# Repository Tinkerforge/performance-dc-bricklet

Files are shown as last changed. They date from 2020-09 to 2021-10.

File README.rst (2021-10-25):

Performance DC Bricklet
=======================

This repository contains the firmware source code and the hardware design
files. The documentation generator configs can be found at
https://github.com/Tinkerforge/generators

Repository Content
------------------

software/:
 * examples/: Examples for all supported languages
 * build/: Compiled files
 * src/: Source code of firmware
 * Makefile: Makefile to build project

hardware/:
 * Contains KiCad project files and additionally schematics as PDF

datasheets/:
 * Contains datasheets for sensors and complex ICs that are used

Hardware
--------

The hardware is designed with the open source EDA Suite KiCad
(http://www.kicad.org). Before you are able to open the files,
you have to install the Tinkerforge kicad-libraries
(https://github.com/Tinkerforge/kicad-libraries). You can either clone
them directly in hardware/ or clone them in a separate folder and
symlink them into hardware/
(ln -s kicad_path/kicad-libraries project_path/hardware). After that you
can open the .pro file in hardware/ with KiCad and from there view and
modify the schematics and the PCB layout.

Software
--------

If you want to do your own Brick/Bricklet firmware development we highly
recommend that you use our build environment setup script and read the
tutorial (https://www.tinkerforge.com/en/doc/Tutorials/Tutorial_Build_Environment/Tutorial.html).

To compile the C code we recommend you to install the newest GNU Arm Embedded
Toolchain (https://launchpad.net/gcc-arm-embedded/+download).
You also need to install bricklib2 (https://github.com/Tinkerforge/bricklib2).

You can either clone it directly in software/src/ or clone it in a
separate folder and symlink it into software/src/
(ln -s bricklib_path/bricklib2 project_path/software/src/). Finally make sure to
have CMake installed (http://www.cmake.org/cmake/resources/software.html).

After that you can build the firmware by invoking make in software/.
The firmware (.zbin) can then be found in software/build/ and uploaded
with brickv (click button "Flashing" on start screen).

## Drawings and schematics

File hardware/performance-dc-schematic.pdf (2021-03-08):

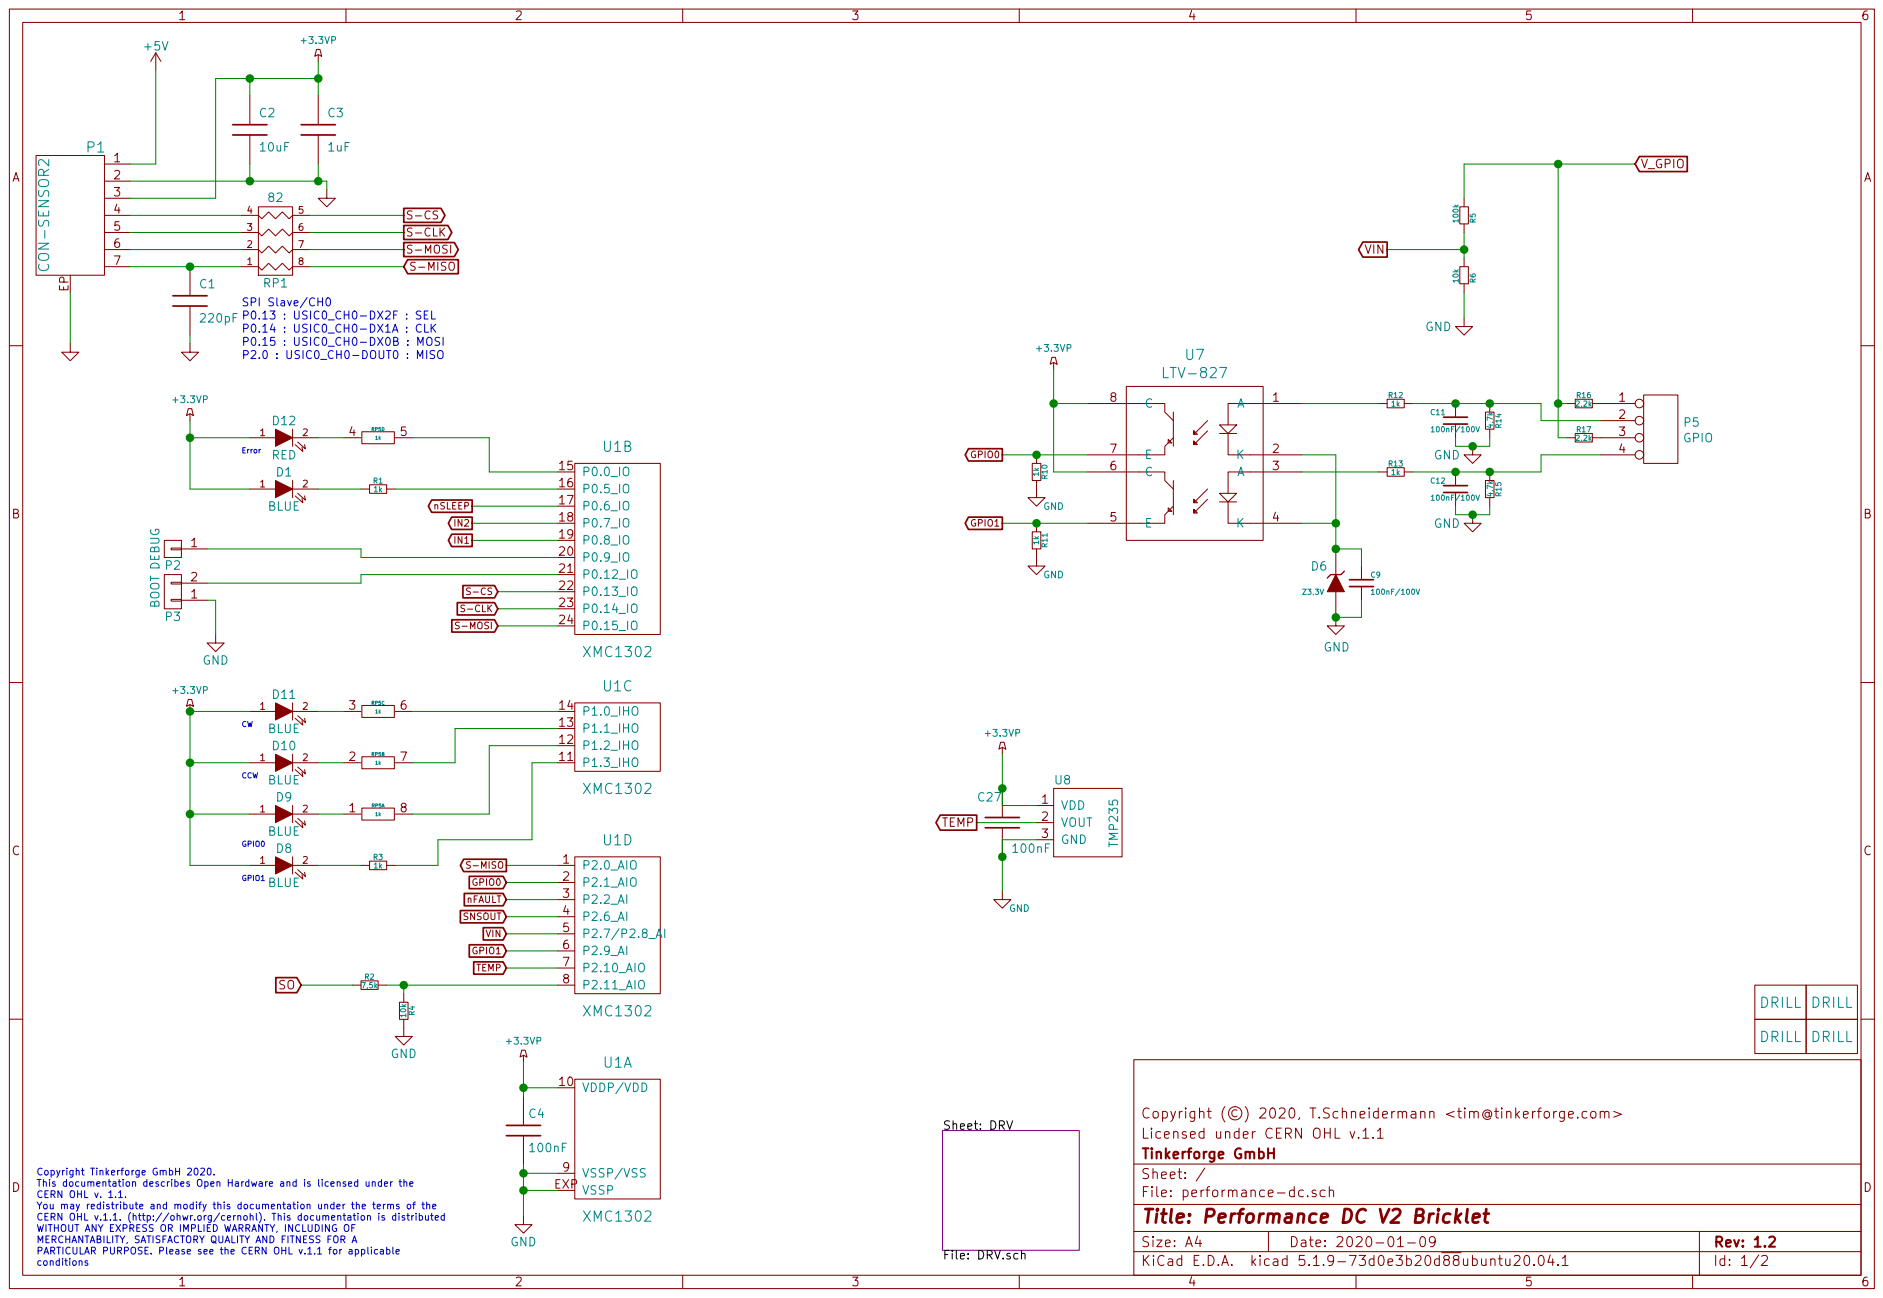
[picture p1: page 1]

SPI Slave/CH0 P0.13 : USIC0_CH0-DX2F : SEL P0.14 : USIC0_CH0-DX1A : CLK

Licensed under CERN OHL v.1.1 Copyright (©) 2020, T.Schneidermann <tim@tinkerforge.com>

File: performance-dc.sch Sheet: / Tinkerforge GmbH

Copyright Tinkerforge GmbH 2020. This documentation describes Open Hardware and is licensed under the CERN OHL v. 1.1. You may redistribute and modify this documentation under the terms of the CERN OHL v.1.1. (http://ohwr.org/cernohl). This documentation is distributed WITHOUT ANY EXPRESS OR IMPLIED WARRANTY, INCLUDING OF MERCHANTABILITY, SATISFACTORY QUALITY AND FITNESS FOR A

Id: 1/2 Title: Performance DC V2 Bricklet

PARTICULAR PURPOSE. Please see the CERN OHL v.1.1 for applicable
conditions

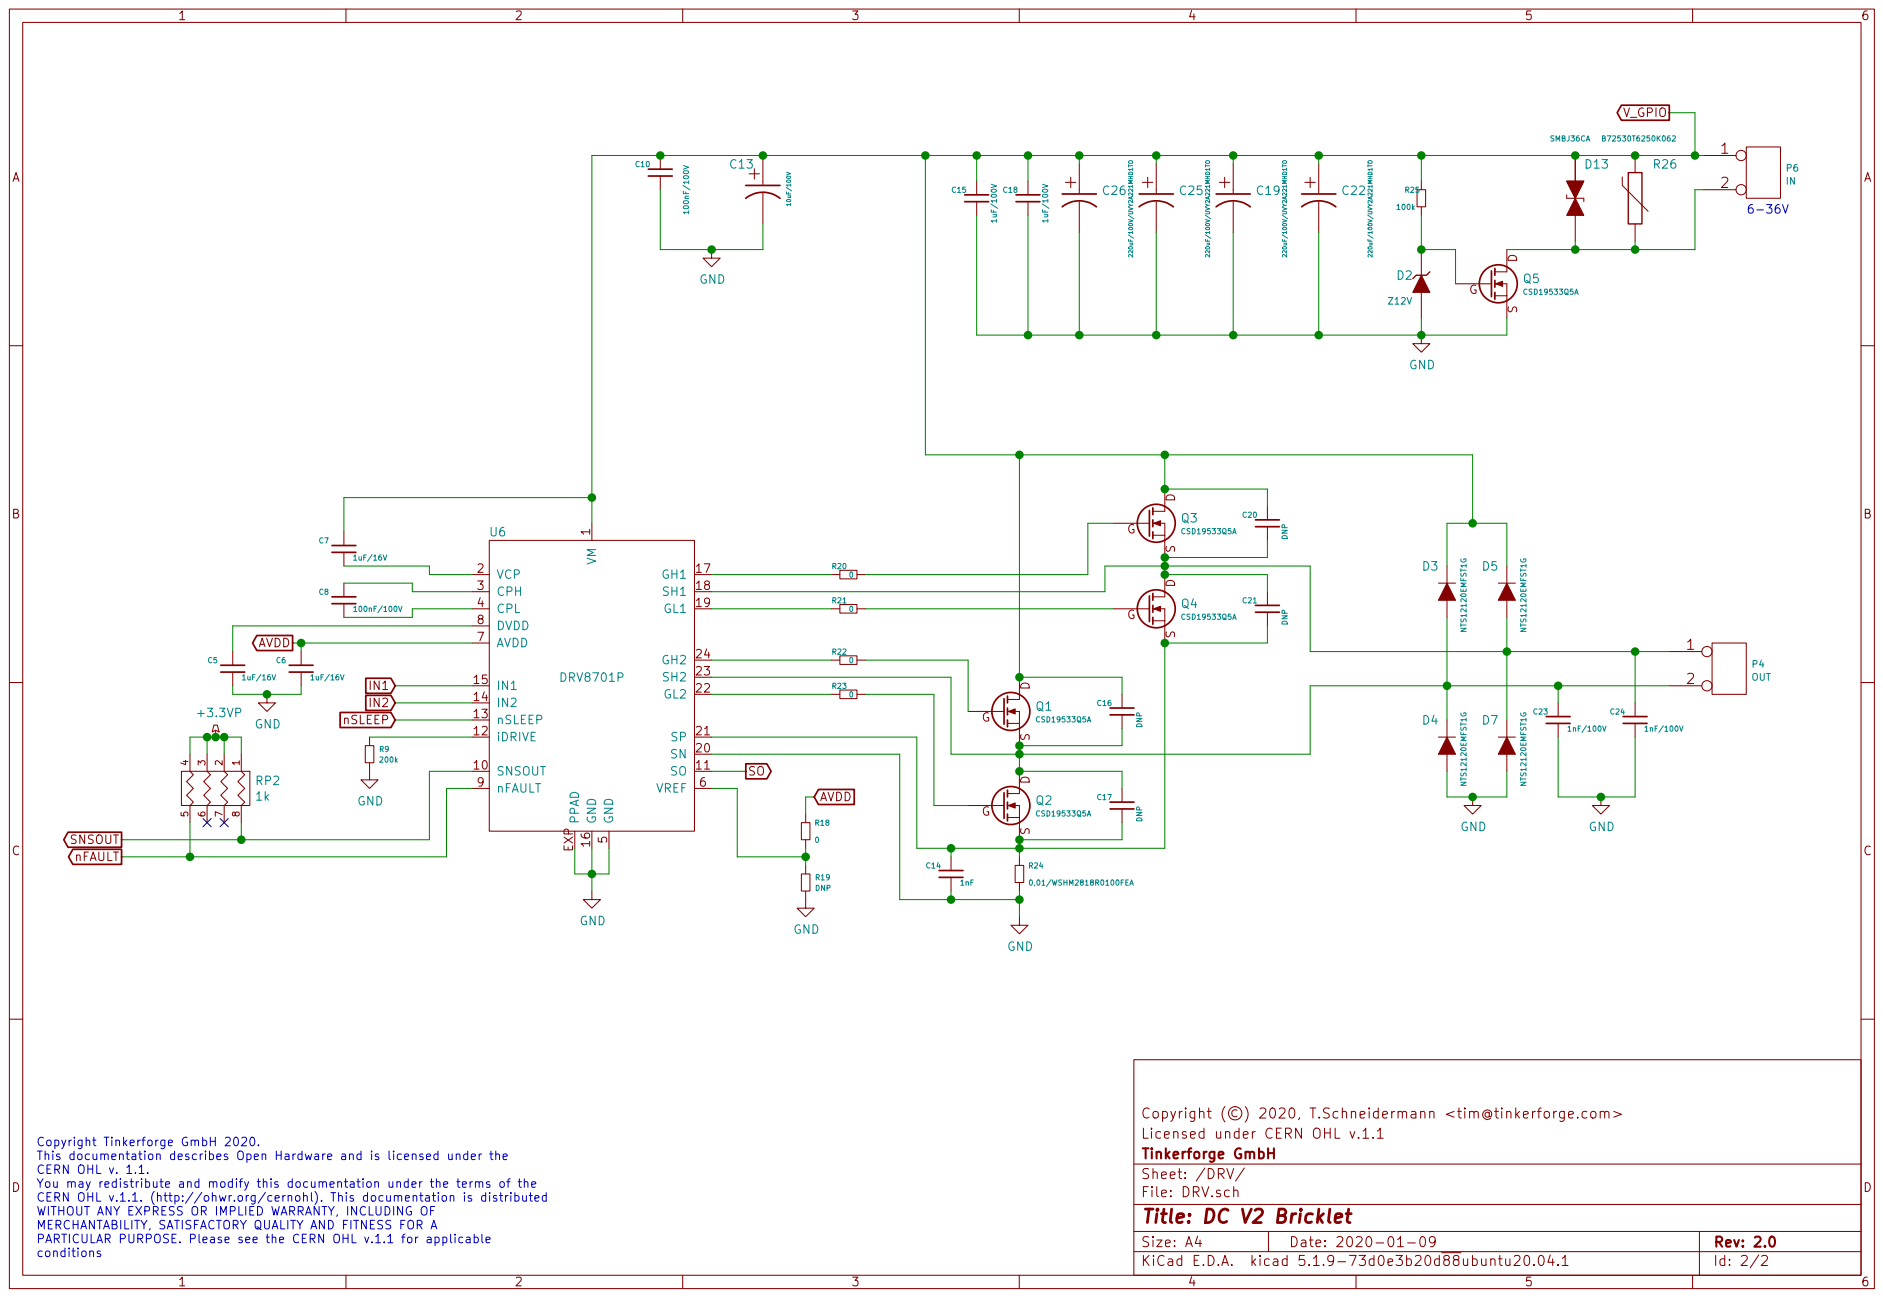
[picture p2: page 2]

Licensed under CERN OHL v.1.1 Copyright (©) 2020, T.Schneidermann <tim@tinkerforge.com>

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

Id: 2/2 Title: DC V2 Bricklet File: DRV.sch Sheet: /DRV/ Tinkerforge GmbH

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

PARTICULAR PURPOSE. Please see the CERN OHL v.1.1 for applicable
conditions

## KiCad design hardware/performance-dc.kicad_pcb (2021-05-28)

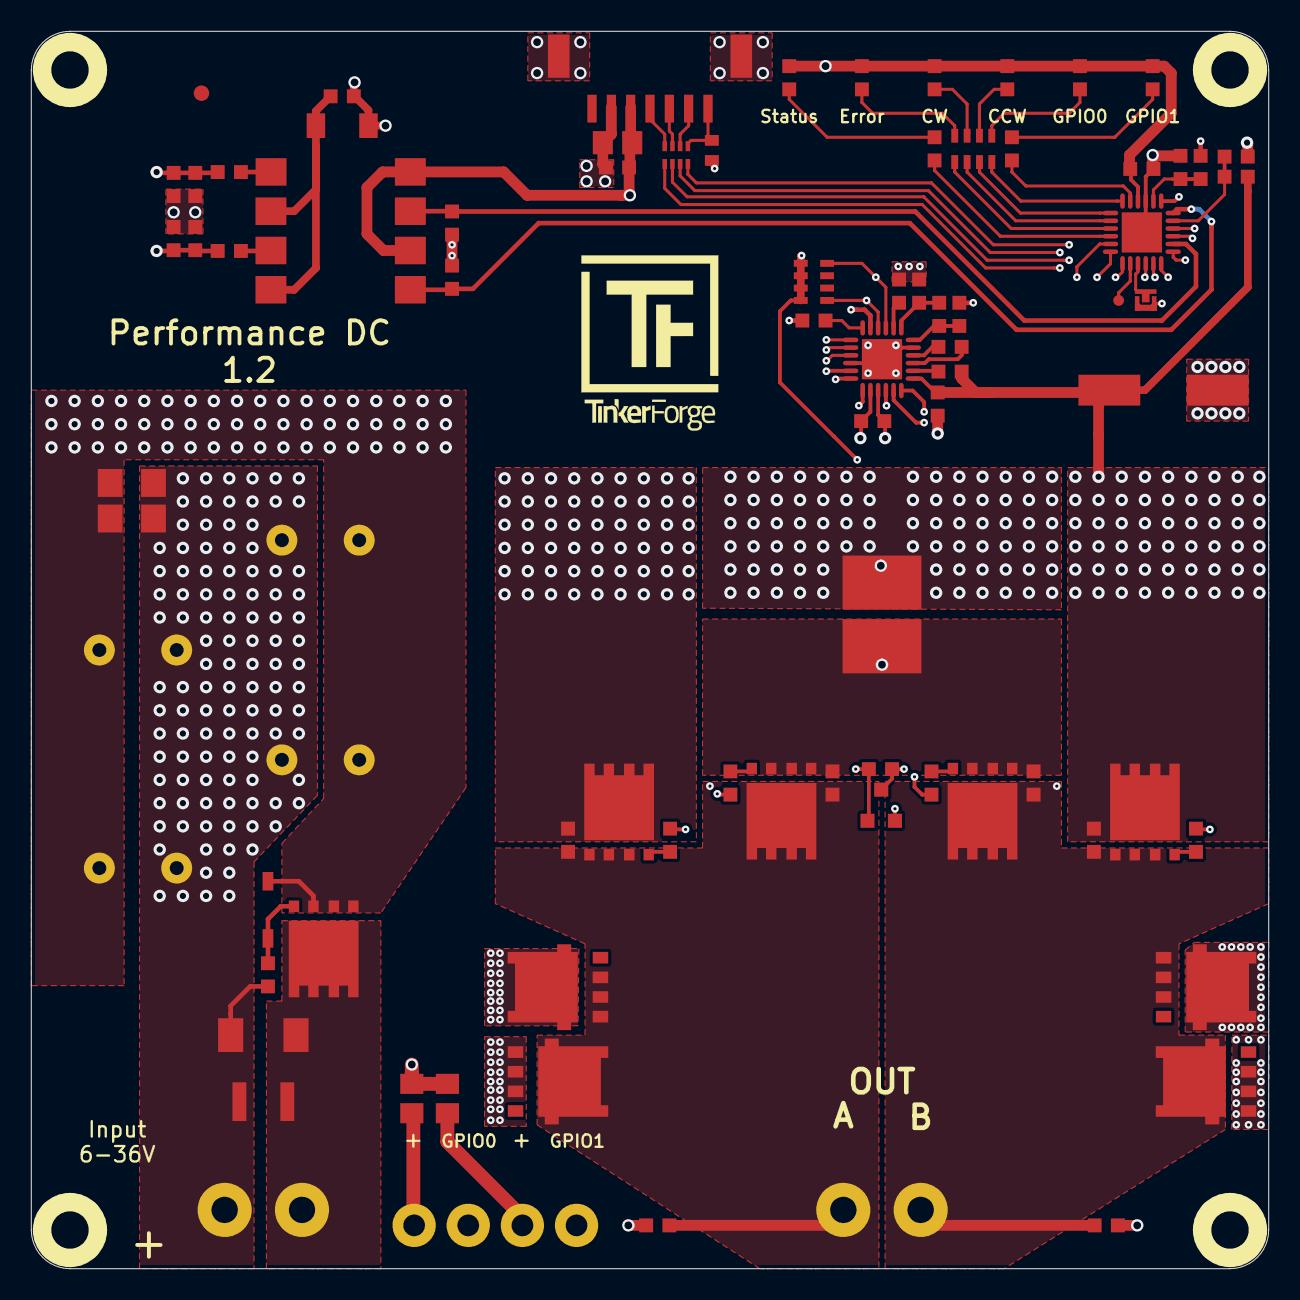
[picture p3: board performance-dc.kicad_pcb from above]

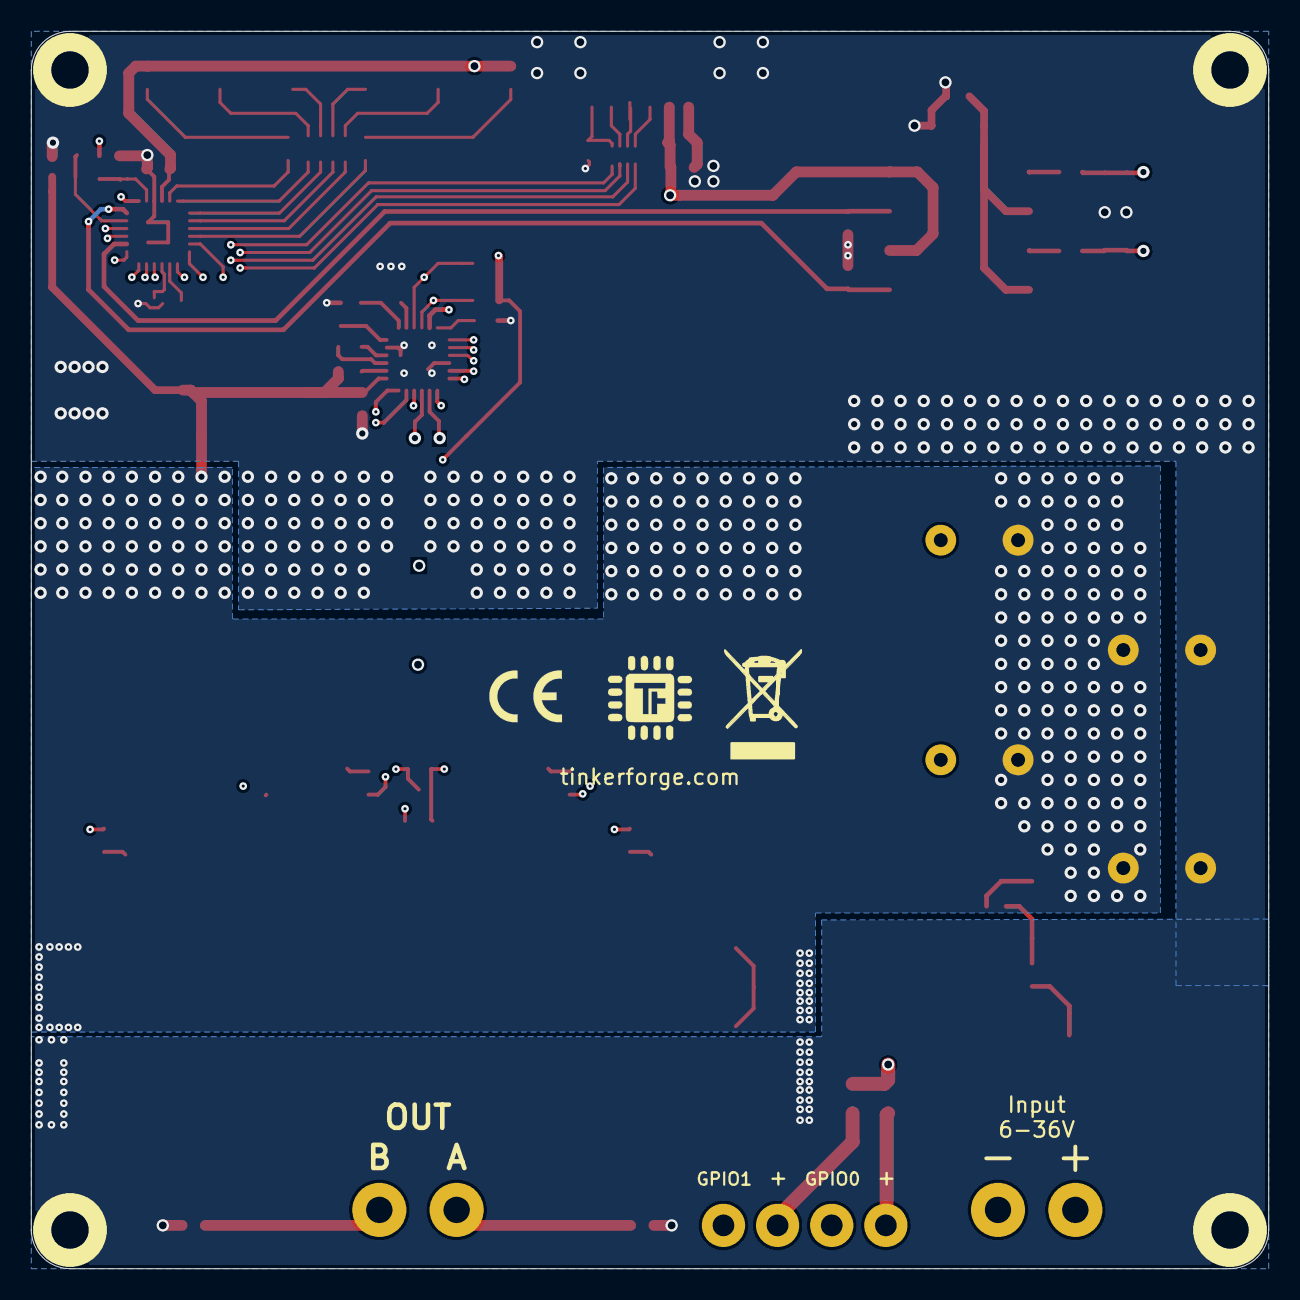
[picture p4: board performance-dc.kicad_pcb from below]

Board: 4 copper layers, 80.0 x 80.0 mm, 89 parts (2 on the bottom side), 63 nets.

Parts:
C1: 220pF; C0402E
C2: 10uF; C0805E
C3: 1uF; C0603F
C4, C27: 100nF; C0603F
C5, C6, C7: 1uF/16V; C0603F
C8, C9, C10, C11, C12: 100nF/100V; C0603F
C13: 10uF/100V; ELKO_83
C14: 1nF; C0603F
C15, C18: 1uF/100V; C1206E
C16, C17, C20, C21: DNP; C0603F
C19, C22, C25, C26: 220uF/100V/UVY2A221MHD1TO; ELKO_RAD_12
C23, C24: 1nF/100V; C0603F
D1, D8, D9, D10, D11: BLUE; D0603F
D2: Z12V; SOD-123
D3, D4, D5, D7: NTS12120EMFST1G; DFN5_5x6
D6: Z3,3V; MiniMelf
D12: RED; D0603F
D13: SMBJ36CA; SMB
Fiducial_Mark: VAL**; Fiducial_Mark
P1: CON-SENSOR2; CON-SENSOR2_180
P2: DEBUG; DEBUG_PAD
P3: BOOT; SolderJumper
P4: OUT; OQ_2P_5mm_Vertical
P5: GPIO; OQ_4P_Vertical
P6: IN; OQ_2P_5mm_Vertical_Black
Q1, Q2, Q3, Q4, Q5: CSD19533Q5A; SON_5x6mm
R1, R3, R10, R11, R12, R13: 1k; R0603F
R2: 7,5k; R0603F
R4, R6: 10k; R0603F
R5, R25: 100k; R0603F
R9: 200k; R0603F
R14, R15: 4,7k; R0603F
R16, R17: 2,2k; R0805E
R18, R20, R21, R22, R23: 0; R0603F
R19: DNP; R0603F
R24: 0,01/WSHM2818R0100FEA; R2818
R26: B72530T6250K062; 1210
RP1: 82; 4X0402
RP2: 1k; 4X0603
RP5: 1k; 0603X4
U1: XMC1302; QFN24-4x4mm-0.5mm
U2, U3, U4, U5: DRILL; DRILL_NP
U6: DRV8701P; QFN24-4x4mm-0.5mm
U7: LTV-827; DIP_8_SMD
U8: TMP235; SOT23-3
VAL: WEEE_7mm
VAL#2: CE_5mm

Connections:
+3.3VP: C2.1, C3.1, C4.1, C27.1, D1.1, D8.1, D9.1, D10.1, D11.1, D12.1, P1.3, RP2.1, RP2.2, RP2.3, RP2.4, U1.10, U7.6, U7.8, U8.1
AVDD: C6.1, R18.1, U6.7
GND: C1.2, C2.2, C3.2, C4.2, C5.2, C6.2, C9.2, C10.2, C11.2, C12.2, C13.2, C14.2, C15.2, C18.2, C19.2, C22.2, C23.2, C24.2, C25.2, C26.2, C27.2, D2.1, D4.1, D6.1, D7.1, P1.2, P1.EP, P3.1, Q5.S, R4.1, R6.2, R9.2, R10.1, R11.1, R14.2, R15.2, R19.2, R24.2, U1.9, U1.EXP, U6.5, U6.16, U6.20, U6.EXP, U8.3
GPIO0: R10.2, U1.2, U7.7
GPIO1: R11.2, U1.6, U7.5
IN1: U1.19, U6.15
IN2: U1.18, U6.14
unnamed: C1.1, P1.7, RP1.1
unnamed: C5.1, U6.8
unnamed: C7.2, U6.2
unnamed: C8.1, U6.3
unnamed: C8.2, U6.4
unnamed: C9.1, D6.2, U7.2, U7.4
unnamed: C11.1, P5.2, R12.1, R14.1
unnamed: C12.1, P5.4, R13.1, R15.1
unnamed: C14.1, C17.2, C21.2, Q2.S, Q4.S, R24.1, U6.21
unnamed: C16.2, C17.1, C23.1, D3.1, D4.2, P4.2, Q1.S, Q2.D, U6.23
unnamed: C20.2, C21.1, C24.1, D5.1, D7.2, P4.1, Q3.S, Q4.D, U6.18
unnamed: D1.2, R1.2
unnamed: D2.2, Q5.G, R25.2
unnamed: D8.2, R3.2
unnamed: D9.2, RP5.1
unnamed: D10.2, RP5.2
unnamed: D11.2, RP5.3
unnamed: D12.2, RP5.4
unnamed: D13.2, P6.2, Q5.D, R26.2
unnamed: P1.4, RP1.4
unnamed: P1.5, RP1.3
unnamed: P1.6, RP1.2
unnamed: P2.1, U1.20
unnamed: P3.2, U1.21
unnamed: P5.1, R16.1
unnamed: P5.3, R17.1
unnamed: Q1.G, R22.1
unnamed: Q2.G, R23.1
unnamed: Q3.G, R20.1
unnamed: Q4.G, R21.1
unnamed: R1.1, U1.16
unnamed: R2.1, R4.2, U1.8
unnamed: R3.1, U1.11
unnamed: R9.1, U6.12
unnamed: R12.2, U7.1
unnamed: R13.2, U7.3
unnamed: R18.2, R19.1, U6.6
unnamed: R20.2, U6.17
unnamed: R21.2, U6.19
unnamed: R22.2, U6.24
unnamed: R23.2, U6.22
unnamed: RP5.5, U1.15
unnamed: RP5.6, U1.14
unnamed: RP5.7, U1.13
unnamed: RP5.8, U1.12
S-CLK: RP1.6, U1.23
S-CS: RP1.5, U1.22
S-MISO: RP1.8, U1.1
S-MOSI: RP1.7, U1.24
SNSOUT: RP2.8, U1.4, U6.10
SO: R2.2, U6.11
TEMP: U1.7, U8.2
VIN: R5.2, R6.1, U1.5
V_GPIO: C7.1, C10.1, C13.1, C15.1, C16.1, C18.1, C19.1, C20.1, C22.1, C25.1, C26.1, D3.2, D5.2, D13.1, P6.1, Q1.D, Q3.D, R5.1, R16.2, R17.2, R25.1, R26.1, U6.1
nFAULT: RP2.5, U1.3, U6.9
nSLEEP: U1.17, U6.13

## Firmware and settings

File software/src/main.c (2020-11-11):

/* performance-dc-bricklet
 * Copyright (C) 2019 Olaf Lüke <olaf@tinkerforge.com>
 *
 * main.c: Initialization for Performance DC Bricklet
 *
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
 * You should have received a copy of the GNU Lesser General Public
 * License along with this library; if not, write to the
 * Free Software Foundation, Inc., 59 Temple Place - Suite 330,
 * Boston, MA 02111-1307, USA.
 */

#include <stdio.h>
#include <stdbool.h>

#include "configs/config.h"

#include "bricklib2/bootloader/bootloader.h"
#include "bricklib2/hal/system_timer/system_timer.h"
#include "bricklib2/logging/logging.h"
#include "communication.h"
#include "drv8701.h"
#include "gpio.h"
#include "voltage.h"

int main(void) {
	logging_init();
	logd("Start DC Bricklet 2.0\n\r");

	communication_init();
	drv8701_init();
	gpio_init();
	voltage_init();

	while(true) {
		bootloader_tick();
		communication_tick();
		drv8701_tick();
		gpio_tick();
		voltage_tick();
	}
}

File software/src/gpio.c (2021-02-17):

/* performance-dc-bricklet
 * Copyright (C) 2020-2021 Olaf Lüke <olaf@tinkerforge.com>
 *
 * gpio.c: Driver for Performance DC Bricklet GPIO
 *
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
 * You should have received a copy of the GNU Lesser General Public
 * License along with this library; if not, write to the
 * Free Software Foundation, Inc., 59 Temple Place - Suite 330,
 * Boston, MA 02111-1307, USA.
 */

#include "gpio.h"
#include "configs/config_gpio.h"

#include "communication.h"
#include "drv8701.h"

#include "bricklib2/hal/system_timer/system_timer.h"
#include "bricklib2/logging/logging.h"

#include "xmc_gpio.h"
#include "xmc_eru.h"

#define gpio_0_handler IRQ_Hdlr_4
#define gpio_1_handler IRQ_Hdlr_6

typedef struct {
	XMC_GPIO_PORT_t *const port;
	const uint8_t pin;
	uint8_t irq_n;
} GPIOPins;

static const GPIOPins gpio_pins[GPIO_CHANNEL_NUM] = {
	{GPIO_0_PIN, GPIO_0_IRQ_N},
	{GPIO_1_PIN, GPIO_1_IRQ_N}
};

static const GPIOPins gpio_led_pins[GPIO_CHANNEL_NUM] = {
	{GPIO_0_LED_PIN, 0},
	{GPIO_1_LED_PIN, 0}
};

GPIO gpio;

static inline void __attribute__((optimize("-O3"))) __attribute__ ((section (".ram_code"))) handle_new_gpio_value(const uint8_t channel) {
	// Check if value changed
	const bool value = XMC_GPIO_GetInput(gpio_pins[channel].port, gpio_pins[channel].pin);
	if(gpio.last_interrupt_value[channel] == value) {
		return;
	}

	// Save value
	gpio.last_interrupt_value[channel] = value;

	// Turn interrupt off if debounce is enabled
	if(gpio.debounce[channel] != 0) {
		gpio.last_interrupt_time[channel]  = system_timer_get_ms();
		NVIC_DisableIRQ(gpio_pins[channel].irq_n);
		NVIC_ClearPendingIRQ(gpio_pins[channel].irq_n);
	}

	// Check for callback
	if(( value && (gpio.action[channel] & PERFORMANCE_DC_GPIO_ACTION_CALLBACK_RISING_EDGE)) ||
	   (!value && (gpio.action[channel] & PERFORMANCE_DC_GPIO_ACTION_CALLBACK_FALLING_EDGE))) {
		gpio.new_callback = true;
	}

	// Check if action is necessary
	if(value && (gpio.action[channel] & PERFORMANCE_DC_GPIO_ACTION_FULL_BRAKE_RISING_EDGE)) {
		gpio.stop_emergency  = true;
		drv8701.full_brake   = true;
	} else if(value && (gpio.action[channel] & PERFORMANCE_DC_GPIO_ACTION_NORMAL_STOP_RISING_EDGE)) {
		gpio.stop_normal     = true;
		drv8701.deceleration = gpio.stop_deceleration[channel];
		drv8701.velocity     = 0;
	} else if(!value && (gpio.action[channel] & PERFORMANCE_DC_GPIO_ACTION_FULL_BRAKE_FALLING_EDGE)) {
		gpio.stop_emergency  = true;
		drv8701.full_brake   = true;
	} else if(!value && (gpio.action[channel] & PERFORMANCE_DC_GPIO_ACTION_NORMAL_STOP_FALLING_EDGE)) {
		gpio.stop_normal     = true;
		drv8701.deceleration = gpio.stop_deceleration[channel];
		drv8701.velocity     = 0;
	}

	// Set LED
	if(gpio.gpio_led_flicker_state[channel].config == PERFORMANCE_DC_GPIO_LED_CONFIG_SHOW_GPIO_ACTIVE_HIGH) {
		if(value) {
			XMC_GPIO_SetOutputLow(gpio_led_pins[channel].port, gpio_led_pins[channel].pin);
		} else {
			XMC_GPIO_SetOutputHigh(gpio_led_pins[channel].port, gpio_led_pins[channel].pin);
		}
	} else if(gpio.gpio_led_flicker_state[channel].config == PERFORMANCE_DC_GPIO_LED_CONFIG_SHOW_GPIO_ACTIVE_LOW) {
		if(value) {
			XMC_GPIO_SetOutputHigh(gpio_led_pins[channel].port, gpio_led_pins[channel].pin);
		} else {
			XMC_GPIO_SetOutputLow(gpio_led_pins[channel].port, gpio_led_pins[channel].pin);
		}
	}
}

void __attribute__((optimize("-O3"))) __attribute__ ((section (".ram_code"))) gpio_0_handler(void) {
	handle_new_gpio_value(0);
}

void __attribute__((optimize("-O3"))) __attribute__ ((section (".ram_code"))) gpio_1_handler(void) {
	handle_new_gpio_value(1);
}
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

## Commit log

2019-09-03 initial push
    [dc.kicad_pcb, dc.sch]
2019-09-03 first protoype schematic
    [dc.sch]
2020-01-15 added schematics
    [dc.sch]
2020-01-16 first pcb layout idea
    [dc.kicad_pcb, dc.sch]
2020-02-05 ready for prototype
    [dc.kicad_pcb, dc.sch]
2020-02-06 drc check and ordered prototype
    [dc.kicad_pcb]
2020-04-09 new DRV8701 design
    [DRV.sch, dc.kicad_pcb, dc.sch]
2020-04-09 changes in schematic
    [DRV.sch, dc.sch]
2020-04-14 new design
    [DRV.sch, dc.kicad_pcb, dc.sch]
2020-04-21 safety save
    [dc.kicad_pcb]
2020-04-24 added input voltage to silkscreen and drc
    [dc.kicad_pcb]
2020-05-08 changed resistor footprint
    [DRV.sch, dc.kicad_pcb, dc.sch]
2020-06-05 Add initial firmware for DC Bricklet 2.0
    (currently still in development)
    [cmake_config_custom.txt]
2020-06-09 Fix device name
2020-07-08 added temperature sensor, and changed protection diodes
    [DRV.sch, dc.kicad_pcb, dc.sch]
2020-07-23 new hardware version
    [dc.kicad_pcb, dc.sch]
2020-08-06 changed mosfet pin 1 on fab layer
    [dc.kicad_pcb]
2020-08-06 added logos to back silkscreen
    [dc.kicad_pcb]
2020-09-08 changed input voltage silkscreen
    [dc.kicad_pcb]
2020-09-08 Add support for temperature sensor
2020-09-09 Version 2.2 : changed name, changed silkscreen, added resistor value for Vref
    [DRV.sch, performance-dc-v2.kicad_pcb, performance-dc-v2.sch]
2020-09-09 changed name and silkscreen ro Version 1.2
    [performance-dc-v2.kicad_pcb, performance-dc.kicad_pcb, performance-dc.sch]
2020-10-14 updated all OQ connectors with new F.Fab layer
    [performance-dc.kicad_pcb]
2020-10-28 specify processor
    [performance-dc.kicad_pcb, performance-dc.sch]
2020-11-06 specify drv8701p
    [DRV.sch, performance-dc.kicad_pcb]
2020-11-19 Add velocity-reached and thermal-shutdown support
2020-11-19 Remove unused velocity_current variable
    We instead use the high resolution version everywhere
2020-11-20 Add nfault pin fault detection
2021-01-12 Add thermal shutdown as error LED trigger
    [drv8701.c]
2021-01-14 Add examples
    [ExampleConfiguration.nb.txt, example-configuration.txt]
2021-01-15 rust: Fix compiler warning
    [example_callback.rs]
2021-02-17 Set default LED config to active high
2021-03-08 add schematic
2021-05-28 fix 3d path
    [performance-dc.kicad_pcb]
2021-10-25 Update KiCad link
    https://www.kicad.org/blog/2021/10/Avoid-links-to-former-kicad-domain/
2022-04-26 uc: Adapt to bindings changes
    [example_callback.c, example_configuration.c]
